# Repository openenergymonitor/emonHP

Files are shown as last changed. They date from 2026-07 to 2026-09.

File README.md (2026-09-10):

# emonHP - Heat Pump Monitoring

**As of Aug 2026 emonHP2 hardware is not yet released**

## Introduction

_emonHP V2_ is a system for monitoring heat pump operation. It is designed to work with [OpenEnergyMonitor](https://openenergymonitor.org), but can be used as a standalone system.

The system provides the following interfaces:

- MBUS
- RS485
- DHW, pulse, and OneWire (DS218B20 temperature) inputs
- USB-C power 
- 40-pin Raspberry Pi header
- OLED I2C display
- RFM69CW RF transceiver 

The board uses a STM32C031K6U microcontroller

## Getting started

### Getting a board

- Purchase a heat pump monitoring system from the [OpenEnergyMonitor Shop](https://shop.openenergymonitor.com/)
- Build your own!
  - With [KiCad](https://www.kicad.org/) installed, run `./generate.py` in the `pcb` directory (tested on Linux and macOS only) to generate manufacturing files (KiCad PCB, Gerbers, BoM).

### emonHP2

> [!NOTE]
Setting up as an integrated emonHP system requires a Raspberry Pi 4 or 5. These expose extra UART ports on the 40-pin header which are not available on older versions.

Connect the Raspberry Pi to the 40 pin header.

> [!WARNING]
Power must only be applied to one of the emonHP's USB-C port *or* the Raspberry Pi's power port, never both.

### Connections 

- DHW Status: Signal 1 input - GPIO27 - Pin 13 
- Pulse: Signal 2 input - GPIO22 - Pin15 - soft-pull down enabled (NOT TESTED)
- OneWire (DS18B20 ) - Signal 3 input - GPIO0*

\* Set `dtoverlay=w1-gpio,gpiopin=0` in `/boot/firmware/config.txt` to support OneWire on GPIO0

 - Push button - GPIO17 - pin11: set `push_btn = Button(17, pull_up=True, bounce_time=0.1, hold_time=5)` in `emonPiLCD2.py` 

### Firmware & Rasi Setup 

See firmware repo: https://github.com/openenergymonitor/emonhp-rs

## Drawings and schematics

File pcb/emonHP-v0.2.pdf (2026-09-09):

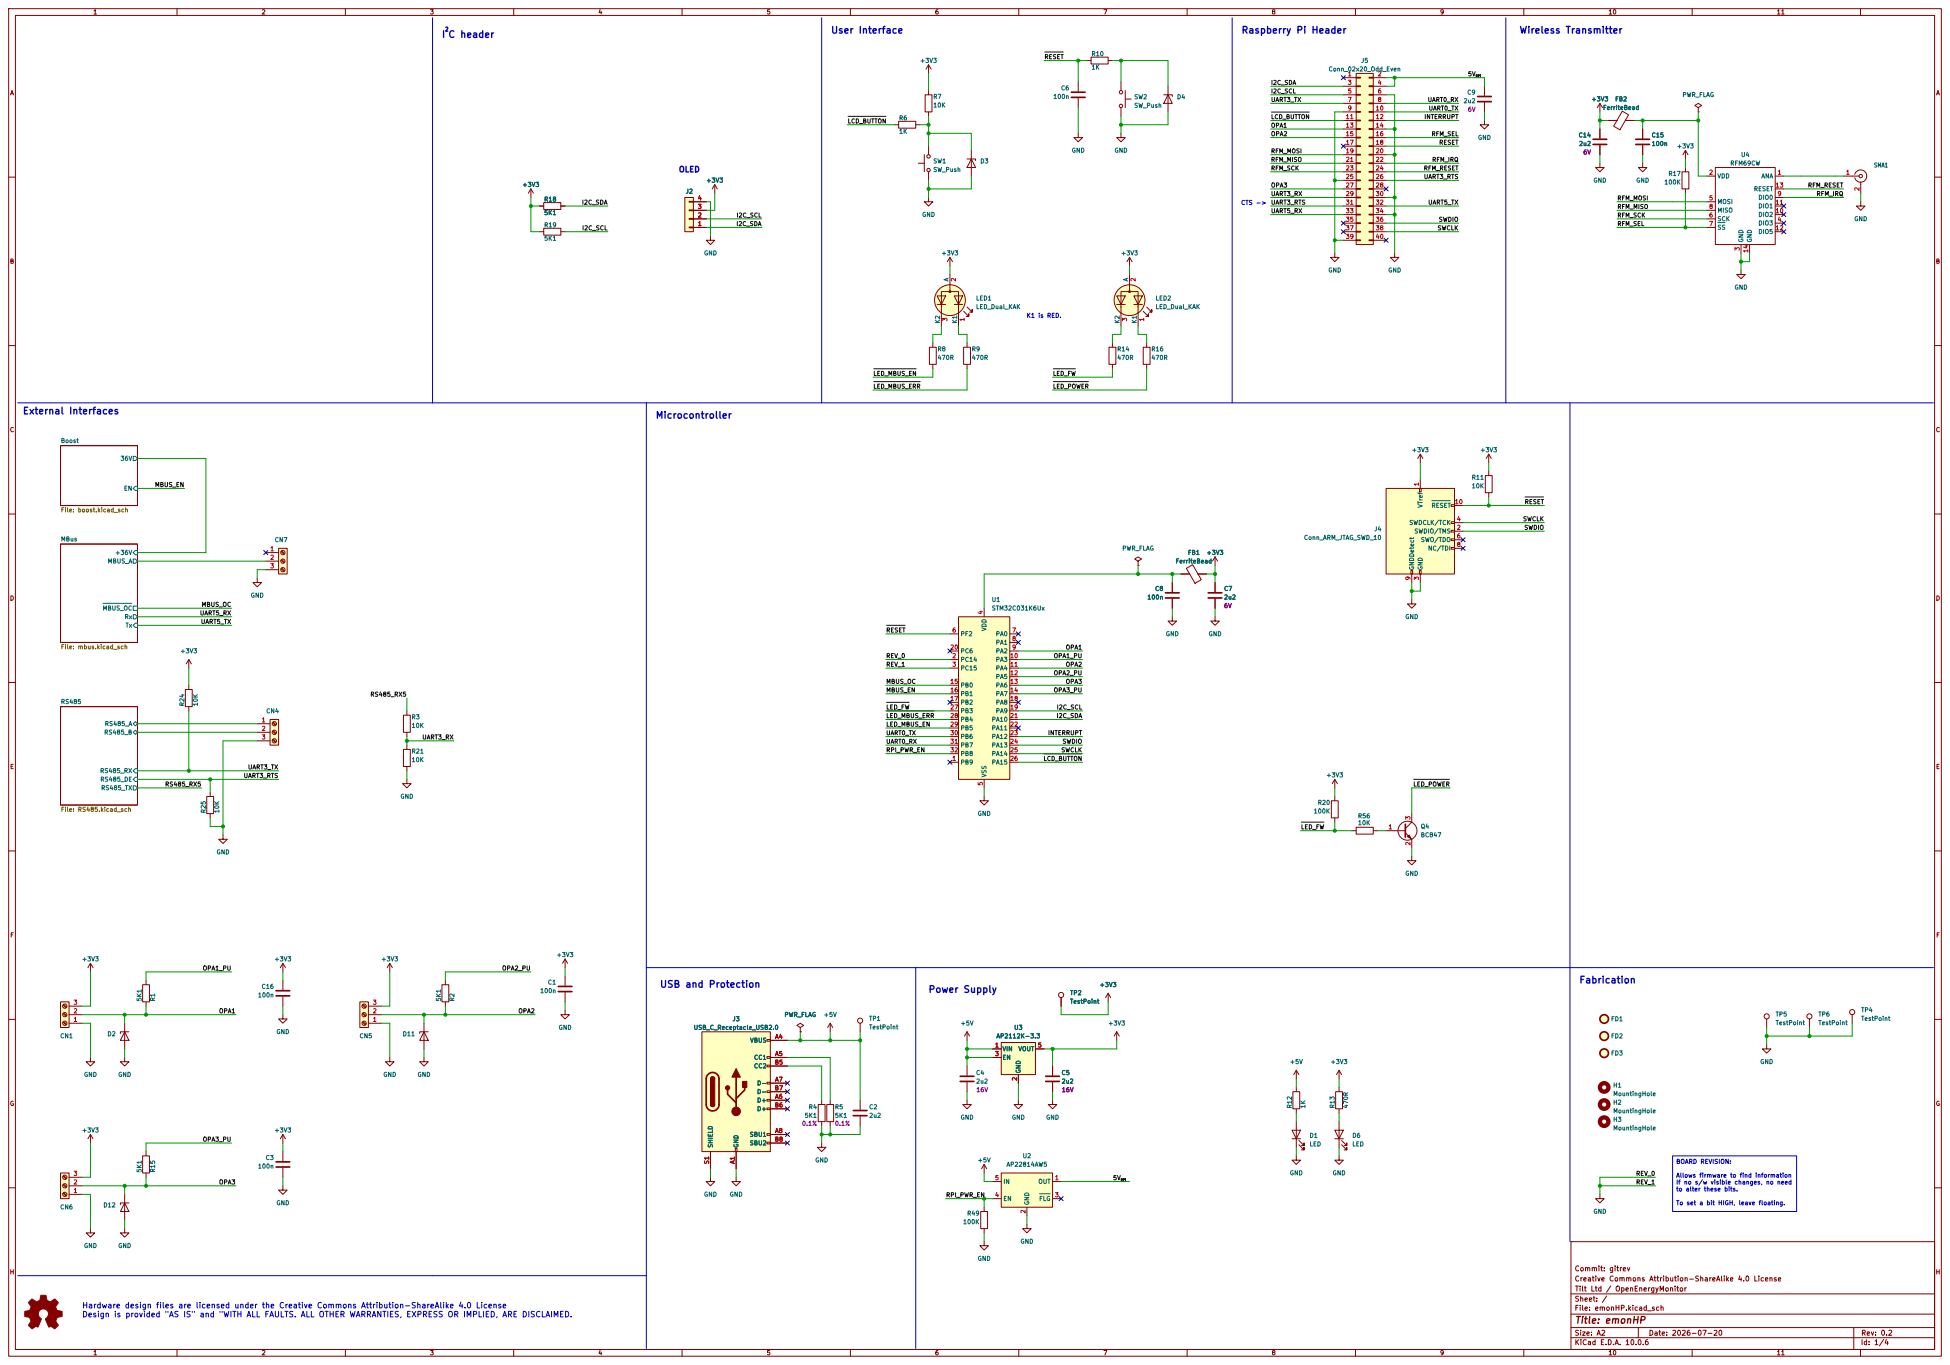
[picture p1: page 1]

USB and Protection PWR_FLAG | TestPoint+3V3 Power Supply TP2 TP2 VOUT 5 U3 AP2112K-3.3 AP2112K-3.3

SBU2 | B8 SHIELD S1

BOARD REVISION: Allows firmware to find information

to alter these bits. To set a bit HIGH, leave floating. Hardware design files are licensed under the Creative Commons Attribution-ShareAlike 4.0 License Design is provided "AS IS" and "WITH ALL FAULTS. ALL OTHER WARRANTIES, EXPRESS OR IMPLIED, ARE DISCLAIMED.

If no s/w visible changes, no need

Tilt Ltd / OpenEnergyMonitor Creative Commons Attribution-ShareAlike 4.0 License Commit: gitrev

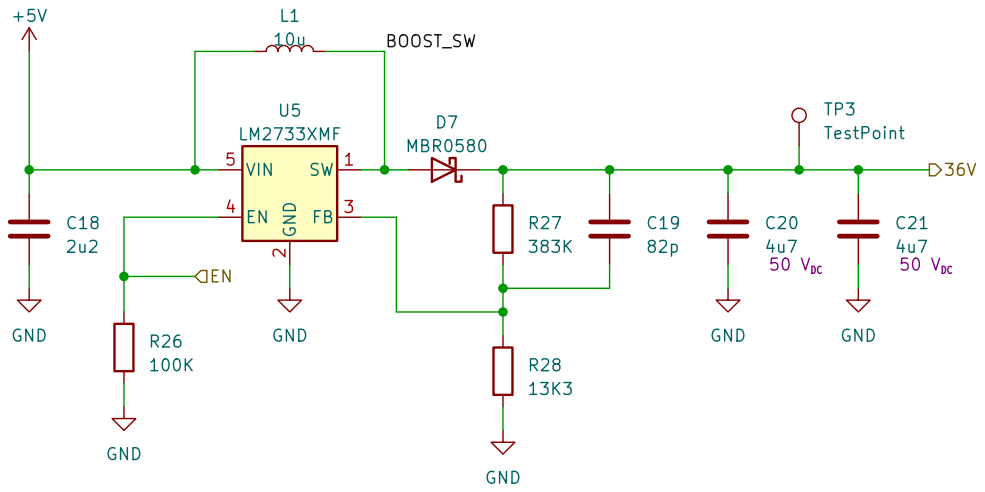
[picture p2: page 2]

File: boost.kicad_sch Sheet: /Boost/

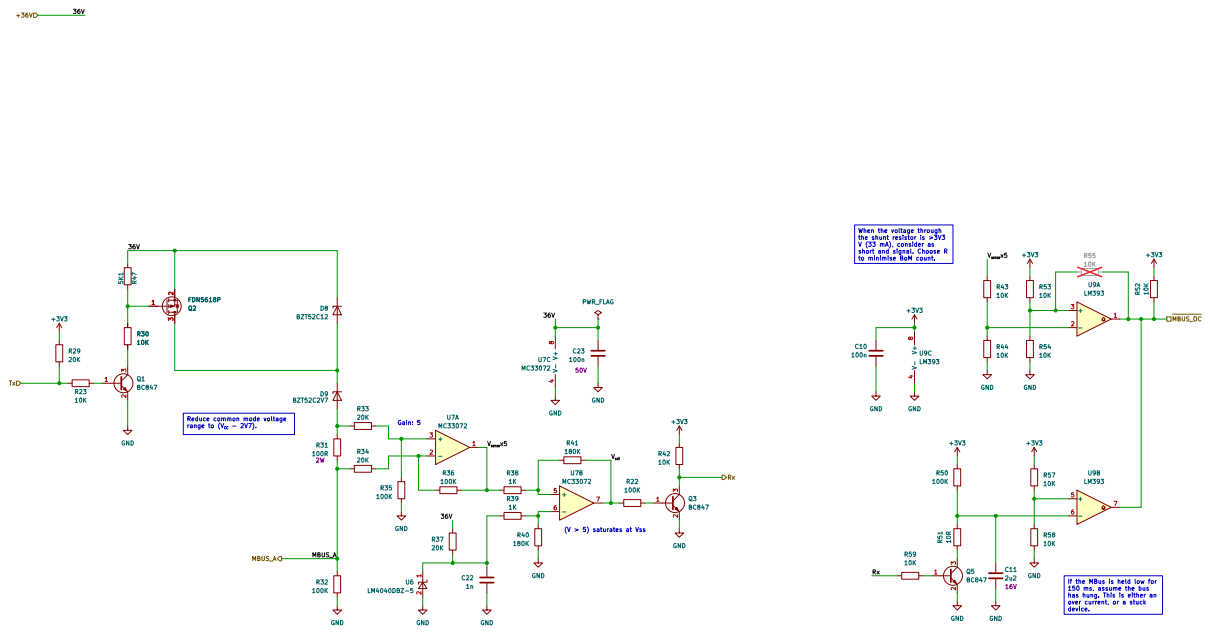
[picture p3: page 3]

the shunt resistor is >3V3
V (33 mA), consider as
short and signal. Choose R
to minimise BoM count.

Vsensex5 Reduce common mode voltage

over current, or a stuck device. (V > 5) saturates at Vss Gain: 5 Q2

If the MBus is held low for 150 ms, assume the bus has hung. This is either an

File: mbus.kicad_sch Sheet: /MBus/

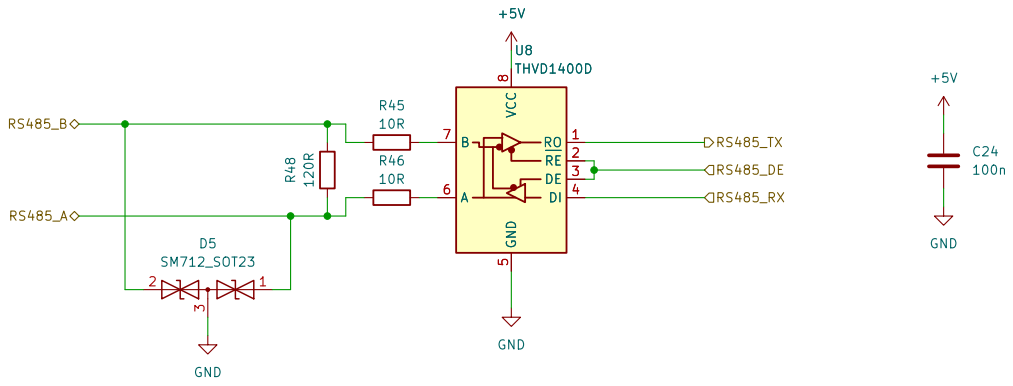
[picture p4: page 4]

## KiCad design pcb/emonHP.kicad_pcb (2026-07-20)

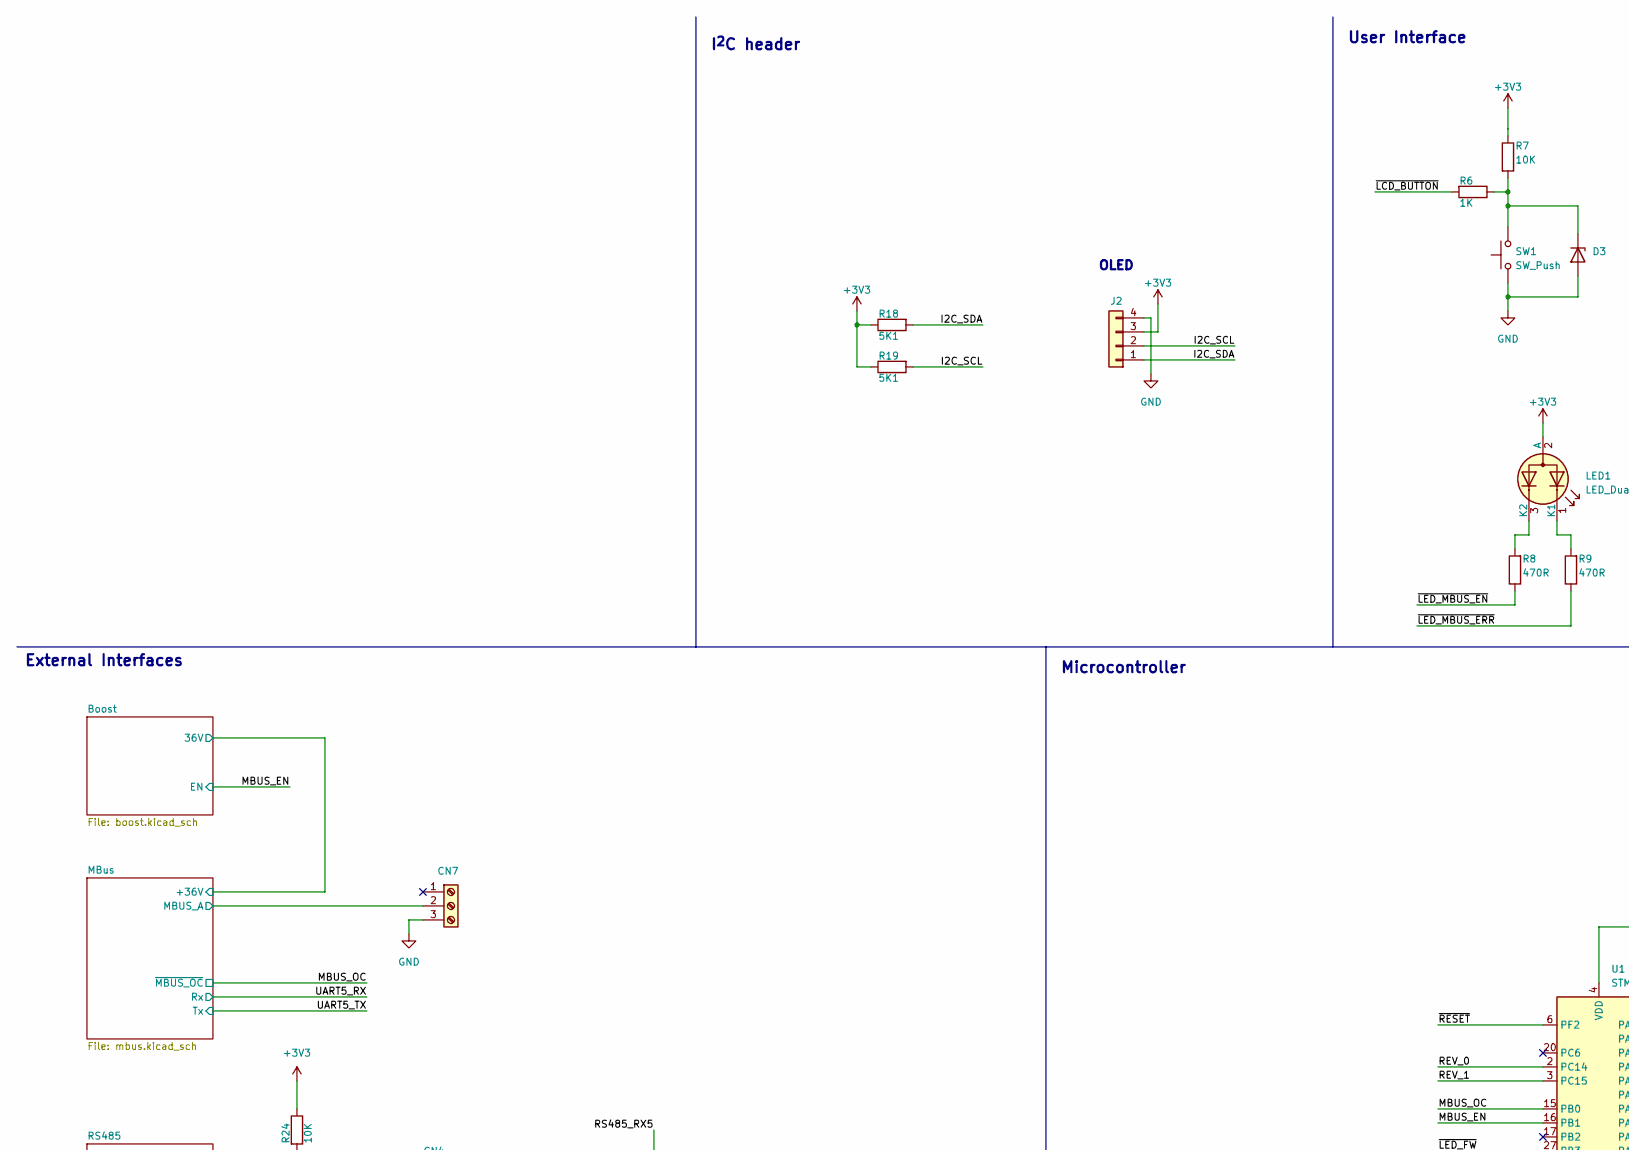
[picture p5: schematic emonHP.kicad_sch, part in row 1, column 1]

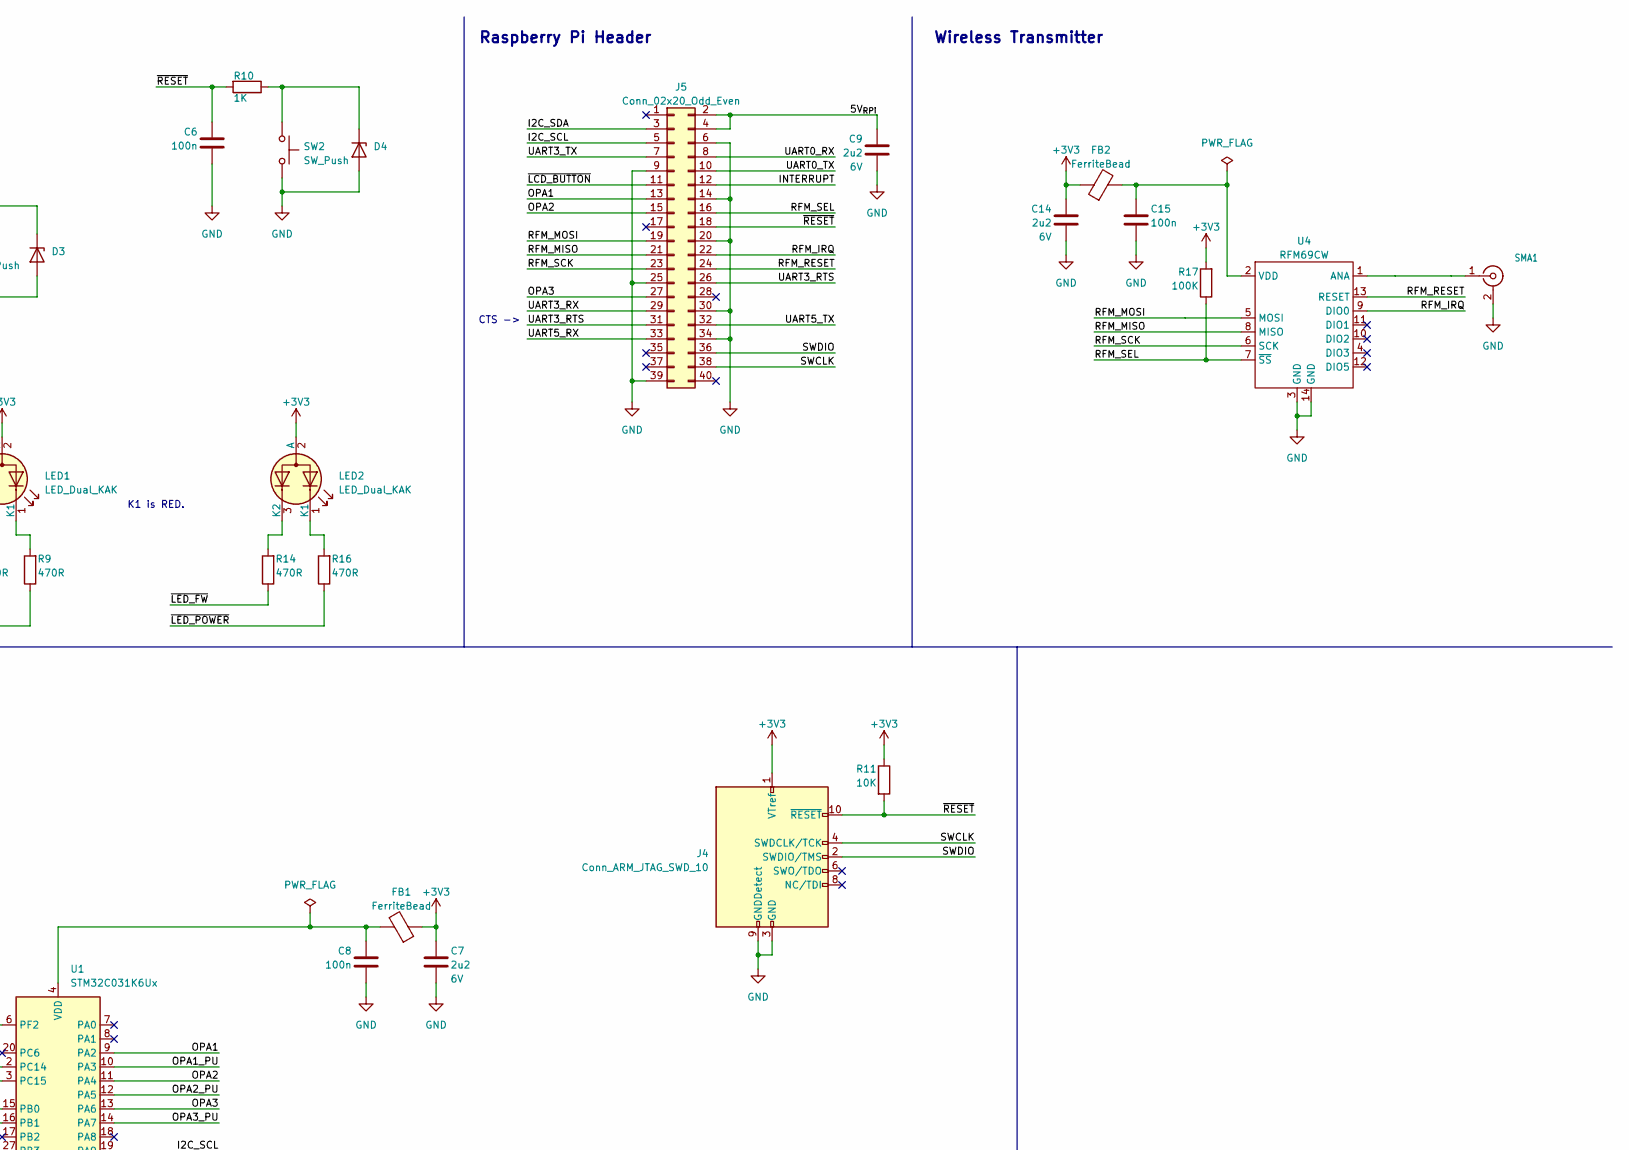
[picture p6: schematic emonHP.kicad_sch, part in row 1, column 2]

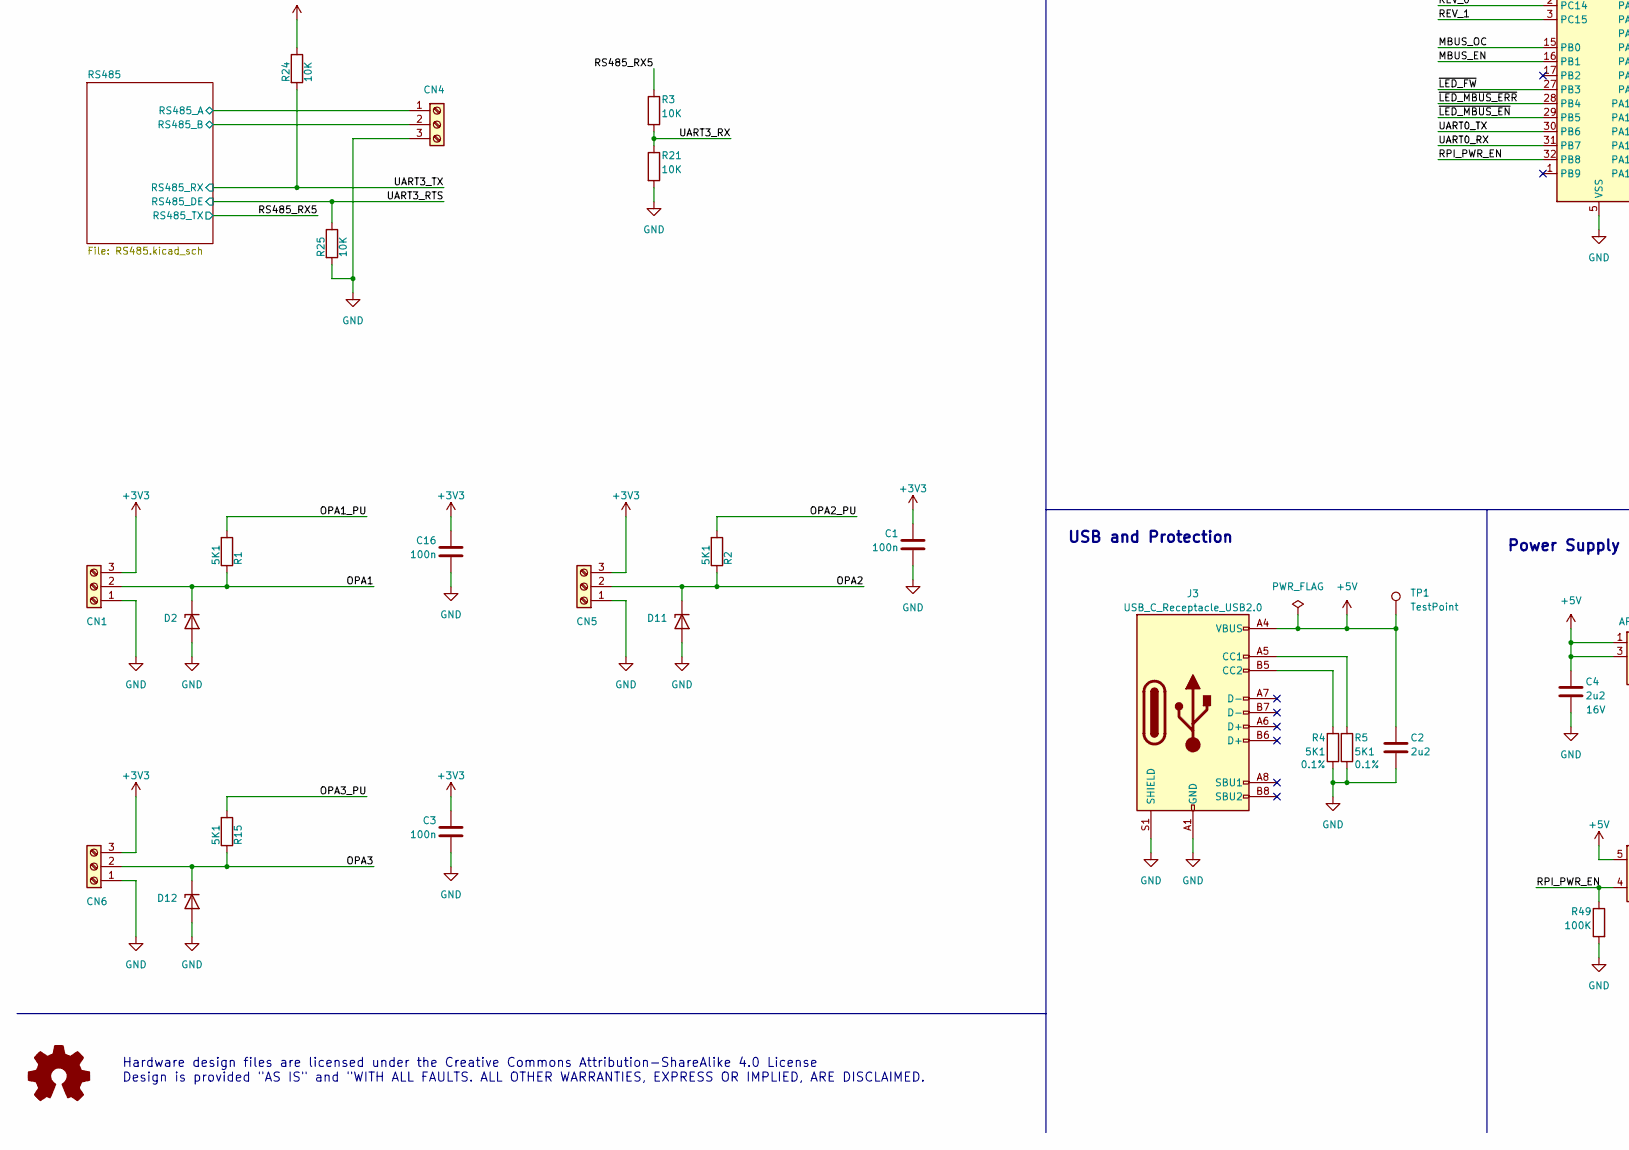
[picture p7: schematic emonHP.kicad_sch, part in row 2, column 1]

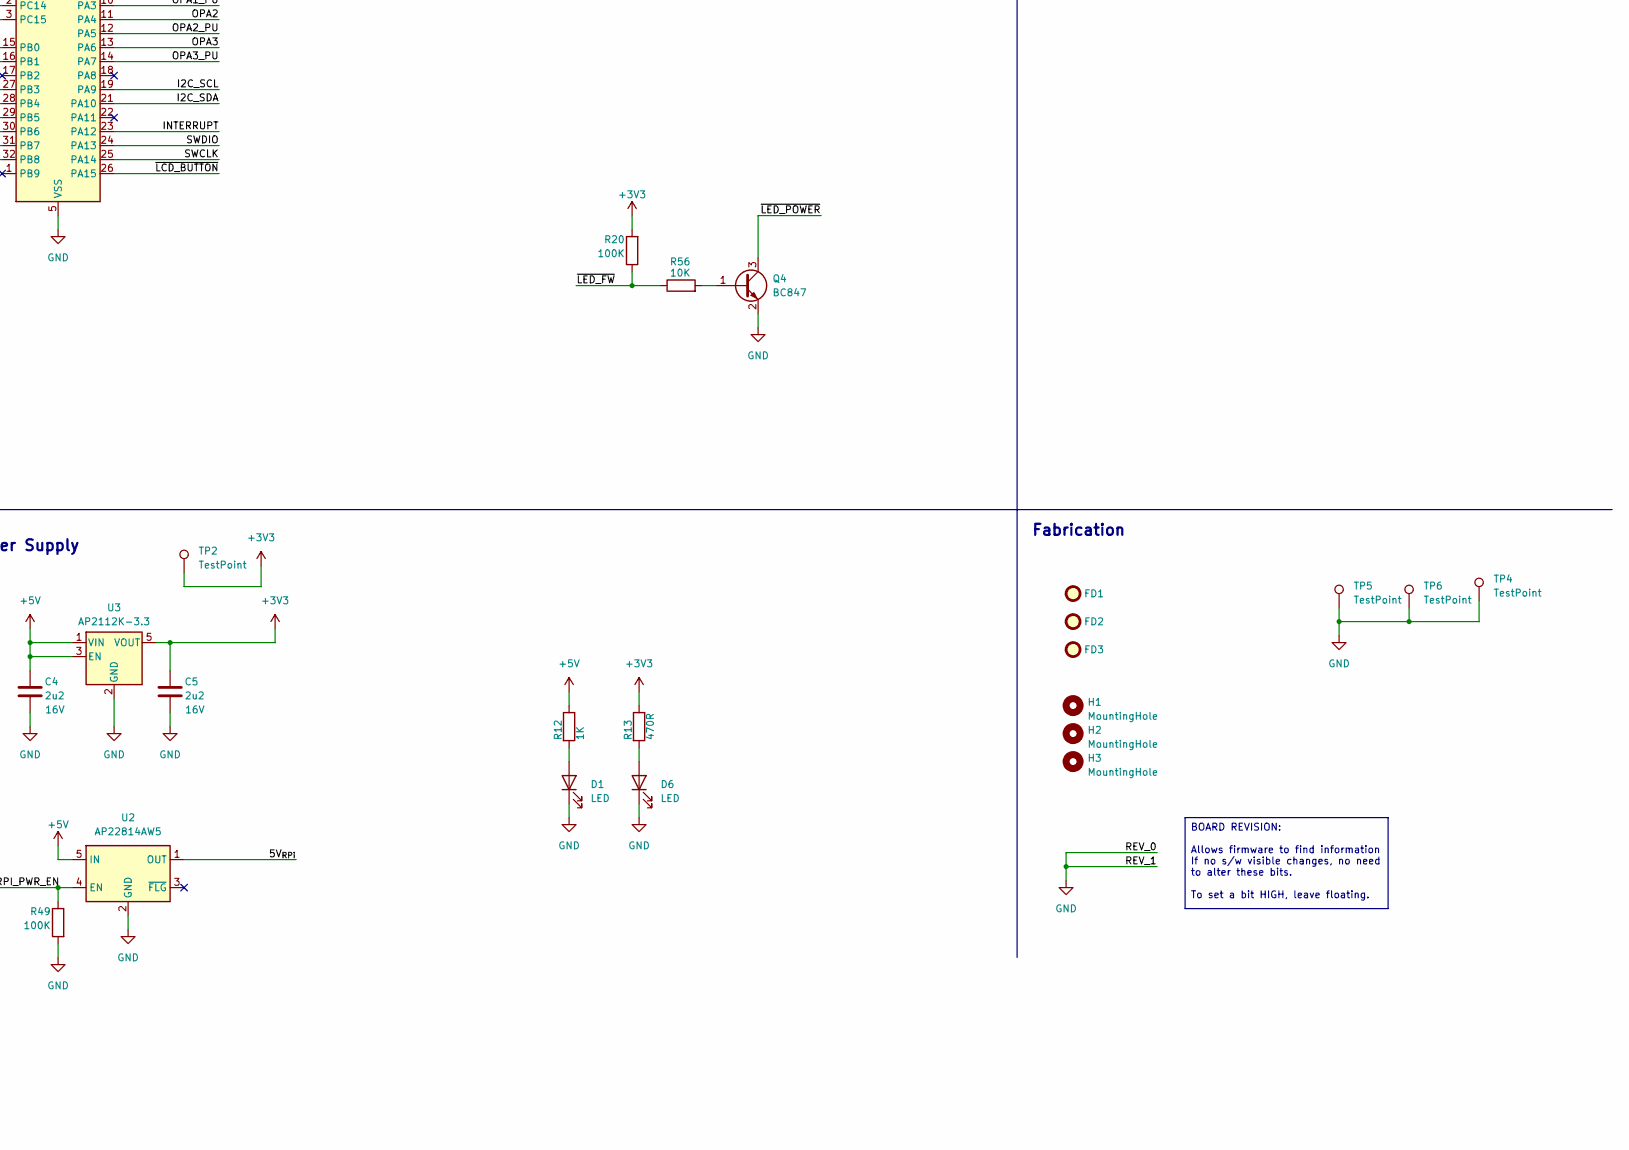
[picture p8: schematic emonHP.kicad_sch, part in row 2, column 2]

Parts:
C1, C3, C6, C8, C15, C16: 100n; C_0402_1005Metric; LCSC C1525
C2: 2u2; C_0402_1005Metric; LCSC C12530
C4, C5: 2u2; C_0603_1608Metric; Voltage 16V; LCSC C23630
C7, C9, C14: 2u2; C_0402_1005Metric; Voltage 6V; LCSC C12530
CN1, CN4, CN5, CN6, CN7: CONN_03SCREW; TerminalBlock_Phoenix_PT-1,5-3-3.5-H_1x03_P3.50mm_Horizontal; MPN 5441359; Mouser 651-5441359
D1, D6: LED; LED_0603_1608Metric; LCSC C2286
D2, D3, D4, D11, D12: ESD5Z3.3T5G; D_SOD-523; LCSC C22440024
FB1, FB2: FerriteBead; R_0402_1005Metric; LCSC C237347
FD1, FD2, FD3: FIDUCIAL1X2; Fiducial_0.75mm_Mask1.5mm
H1, H2: MountingHole; MountingHole_2.7mm_M2.5
H3: MountingHole; MountingHole_2.1mm
J2: CONN_04PTH; PinSocket_1x04_P2.54mm_Vertical
J3: USB_C_Receptacle_USB2.0; CSP-USC16-TR; LCSC C2765186
J4: Conn_ARM_JTAG_SWD_10; PinHeader_2x05_P1.27mm_Vertical_SMD; LCSC C150517
J5: Conn_02x20_Odd_Even; REF-182665; LCSC C9900171940
LED1, LED2: LED_Dual_KAK; LTST-S326; MPN LTST-S326KGJRKT; Mouser 859-LTST-S326KGJRKT
Q4: BC847; SOT-23; LCSC C2138
R1, R2, R15, R18, R19: 5K1; R_0402_1005Metric; LCSC C25905
R3, R7, R11, R21, R24, R25, R56: 10K; R_0402_1005Metric; LCSC C25744
R4, R5: 5K1; R_0402_1005Metric; Tolerance 0.1%; MPN ERA-3AED512V; Mouser 667-ERA-3AED512V
R6, R10, R12: 1K; R_0402_1005Metric; LCSC C11702
R8, R9, R13, R14, R16: 470R; R_0402_1005Metric; LCSC C25117
R17, R20, R49: 100K; R_0402_1005Metric; LCSC C25741
SMA1: SMACONNECTOR; SMA_Amphenol_132203-12_Horizontal
SW1: SW_Push; SW_PUSH_6mm
SW2: SW_Push; SW_Tactile_SPST_NO_Straight_CK_PTS636Sx25SMTRLFS; LCSC C2689642
TP1, TP2, TP4, TP5, TP6: TestPoint; TestPoint_Pad_D1.0mm
U1: STM32C031K6Ux; QFN-32-1EP_5x5mm_P0.5mm_EP3.45x3.45mm; LCSC C5456204
U2: AP22814AW5; SOT-23-5; LCSC C2680321
U3: AP2112K-3.3; SOT-23-5; LCSC C51118
U4: RFM69CW

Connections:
+3V3: C1.1, C3.1, C5.2, C7.1, C14.1, C16.1, CN1.3, CN5.3, CN6.3, FB1.1, FB2.1, J2.3, J4.1 (VTref), LED1.2 (A), LED2.2 (A), R7.1, R11.1, R13.1, R17.2, R18.1, R19.1, R20.2, R24.1, TP2.1, U3.5 (VOUT); also elsewhere on the board
+5V: C2.2, C4.2, J3.A4 (VBUS), J3.A9 (VBUS), J3.B4 (VBUS), J3.B9 (VBUS), R12.1, TP1.1, U2.5 (IN), U3.1 (VIN), U3.3 (EN); also elsewhere on the board
/5V_{RPi}: C9.1, J5.2, J5.4, U2.1 (OUT)
/I2C_SCL: J2.2, J5.5, R19.2, U1.19 (PA9)
/I2C_SDA: J2.1, J5.3, R18.2, U1.21 (PA10)
/INTERRUPT: J5.12, U1.23 (PA12)
/MBUS_EN: U1.16 (PB1); also elsewhere on the board
/MBUS_OC: U1.15 (PB0); also elsewhere on the board
/MBus/MBUS_A: CN7.2; also elsewhere on the board
/OPA1: CN1.2, D2.1 (K), J5.13, R1.1, U1.9 (PA2)
/OPA1_PU: R1.2, U1.10 (PA3)
/OPA2: CN5.2, D11.1 (K), J5.15, R2.1, U1.11 (PA4)
/OPA2_PU: R2.2, U1.12 (PA5)
/OPA3: CN6.2, D12.1 (K), J5.27, R15.1, U1.13 (PA6)
/OPA3_PU: R15.2, U1.14 (PA7)
/RFM_IRQ: J5.22, U4.9 (DIO0)
/RFM_MISO: J5.21, U4.8 (MISO)
/RFM_MOSI: J5.19, U4.5 (MOSI)
/RFM_RESET: J5.24, U4.13 (RESET)
/RFM_SCK: J5.23, U4.6 (SCK)
/RFM_SEL: J5.16, R17.1, U4.7 (~SS)
/RPI_PWR_EN: R49.1, U1.32 (PB8), U2.4 (EN)
/RS485/RS485_A: CN4.1; also elsewhere on the board
/RS485/RS485_B: CN4.2; also elsewhere on the board
/RS485_RX5: R3.1; also elsewhere on the board
/SWCLK: J4.4 (SWDCLK/TCK), J5.38, U1.25 (PA14)
/SWDIO: J4.2 (SWDIO/TMS), J5.36, U1.24 (PA13)
/UART0_RX: J5.8, U1.31 (PB7)
/UART0_TX: J5.10, U1.30 (PB6)
/UART3_RTS: J5.26, J5.31, R25.1; also elsewhere on the board
/UART3_RX: J5.29, R3.2, R21.1
/UART3_TX: J5.7, R24.2; also elsewhere on the board
/UART5_RX: J5.33; also elsewhere on the board
/UART5_TX: J5.32; also elsewhere on the board
/~LCD_BUTTON: J5.11, R6.2, U1.26 (PA15)
/~LED_FW: R14.1, R20.1, R56.1, U1.27 (PB3)
/~LED_MBUS_EN: R8.1, U1.29 (PB5)
/~LED_MBUS_ERR: R9.1, U1.28 (PB4)
/~LED_POWER: Q4.3 (C), R16.1
/~RESET: C6.1, J4.10 (~RESET), J5.18, R10.2, R11.2, U1.6 (PF2)
GND: C1.2, C2.1, C3.2, C4.1, C5.1, C6.2, C7.2, C8.2, C9.2, C14.2, C15.2, C16.2, CN1.1, CN4.3, CN5.1, CN6.1, CN7.3, D1.1 (K), D2.2 (A), D3.2 (A), D4.2 (A), D6.1 (K), D11.2 (A), D12.2 (A), J2.4, J3.A1 (GND), J3.A12 (GND), J3.B1 (GND), J3.B12 (GND), J3.S1 (SHIELD), J4.3 (GND), J4.5 (GND), J4.9 (GNDDetect), J5.6, J5.9, J5.14, J5.20, J5.25, J5.30, J5.34, J5.39, Q4.2 (E), R4.1, R5.1, R21.2, R25.2, R49.2, SMA1.2 (Ext), SW1.1, SW2.2, TP4.1, TP5.1, TP6.1, U1.2 (PC14), U1.3 (PC15), U1.5 (VSS), U1.33 (VSS), U2.2 (GND), U3.2 (GND), U4.3 (GND), U4.14 (GND); also elsewhere on the board
unnamed: D1.2 (A), R12.2
unnamed: D3.1 (K), R6.1, R7.2, SW1.2
unnamed: D4.1 (K), R10.1, SW2.1
unnamed: D6.2 (A), R13.2
unnamed: J3.A5 (CC1), R5.2
unnamed: J3.B5 (CC2), R4.2
unnamed: LED1.1 (K1), R9.2
unnamed: LED1.3 (K2), R8.2
unnamed: LED2.1 (K1), R16.2
unnamed: LED2.3 (K2), R14.2
unnamed: Q4.1 (B), R56.2
unnamed: SMA1.1 (In), U4.1 (ANA)
unnamed: C8.1, FB1.2, U1.4 (VDD)
unnamed: C15.1, FB2.2, U4.2 (VDD)

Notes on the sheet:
Raspberry Pi Header
Power Supply
CTS ->
Hardware design files are licensed under the Creative Commons Attribution-ShareAlike 4.0 License Design is provided "AS IS" and "WITH ALL FAULTS. ALL OTHER WARRANTIES, EXPRESS OR IMPLIED, ARE DISCLAIMED.
Microcontroller
User Interface
K1 is RED.
USB and Protection
Fabrication
OLED
External Interfaces
I^{2}C header
Wireless Transmitter
BOARD REVISION: Allows firmware to find information If no s/w visible changes, no need to alter these bits. To set a bit HIGH, leave floating.

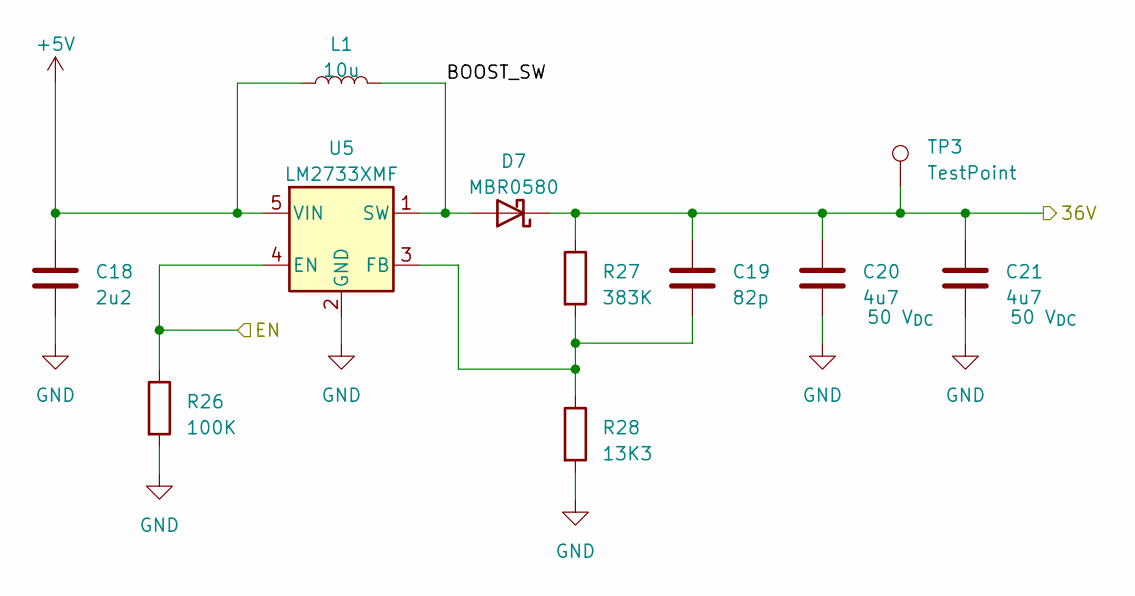
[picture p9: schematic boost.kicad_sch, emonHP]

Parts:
C18: 2u2; C_0603_1608Metric; LCSC C23630
C19: 82p; C_0603_1608Metric; LCSC C1683
C20, C21: 4u7; C_0805_2012Metric; Voltage 50 V_{DC}; MPN GRM21BZ71H475ME15L; LCSC C98192
D7: MBR0580; D_SOD-123; LCSC C177047
L1: 10u; L_Abracon_ASPI-3012S; MPN ASPI-3012S-100M-T; Mouser 815-ASPI-3012S-100MT
R26: 100K; R_0402_1005Metric; LCSC C25741
R27: 383K; R_0402_1005Metric; LCSC C25557
R28: 13K3; R_0402_1005Metric; LCSC C122547
TP3: TestPoint; TestPoint_Pad_D1.0mm
U5: LM2733XMF; SOT-23-5; MPN LM2733XMFX/NOPB; Mouser 926-LM2733XMFX/NOPB

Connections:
+5V: C18.1, L1.2, U5.5 (VIN); also elsewhere on the board
/Boost/BOOST_SW: D7.2 (A), L1.1, U5.1 (SW)
/MBUS_EN: R26.1, U5.4 (EN); also elsewhere on the board
/MBus/36V: C19.1, C20.1, C21.1, D7.1 (K), R27.1, TP3.1; also elsewhere on the board
GND: C18.2, C20.2, C21.2, R26.2, R28.2, U5.2 (GND); also elsewhere on the board
unnamed: C19.2, R27.2, R28.1, U5.3 (FB)

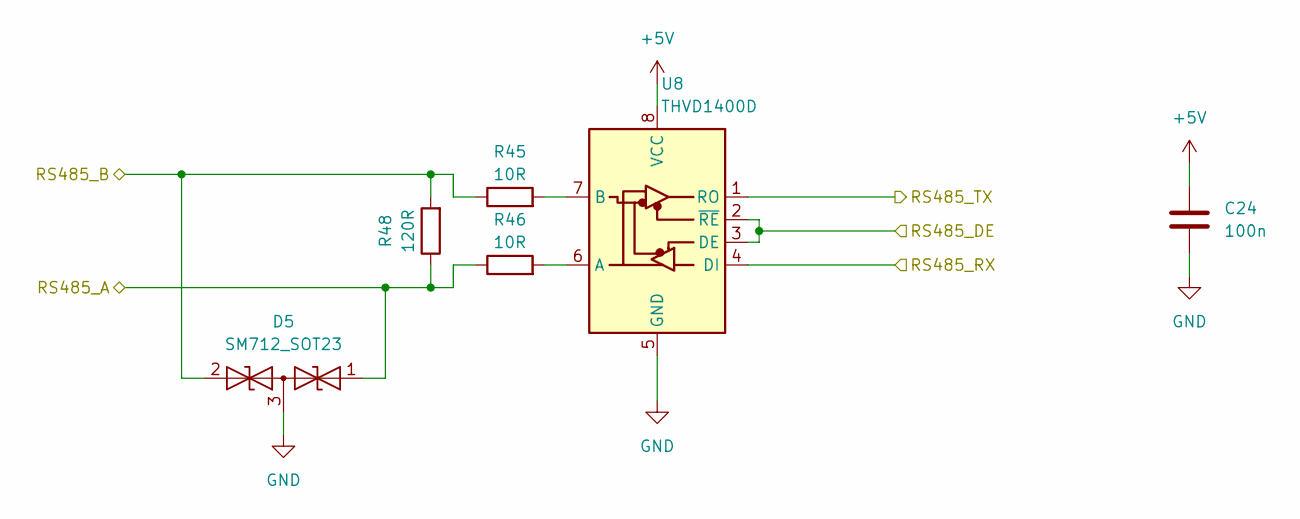
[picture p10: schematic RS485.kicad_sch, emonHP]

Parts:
C24: 100n; C_0402_1005Metric; LCSC C1525
D5: SM712_SOT23; SOT-23; LCSC C172881
R45, R46: 10R; R_0603_1608Metric; LCSC C22859
R48: 120R; R_1206_3216Metric; LCSC C17909
U8: THVD1400D; SOIC-8_3.9x4.9mm_P1.27mm; LCSC C3235232

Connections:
+5V: C24.1, U8.8 (VCC); also elsewhere on the board
/RS485/RS485_A: D5.1 (A1), R46.1, R48.1; also elsewhere on the board
/RS485/RS485_B: D5.2 (A2), R45.1, R48.2; also elsewhere on the board
/RS485_RX5: U8.1 (RO); also elsewhere on the board
/UART3_RTS: U8.2 (~RE), U8.3 (DE); also elsewhere on the board
/UART3_TX: U8.4 (DI); also elsewhere on the board
GND: C24.2, D5.3 (common), U8.5 (GND); also elsewhere on the board
unnamed: R46.2, U8.6 (A)
unnamed: R45.2, U8.7 (B)

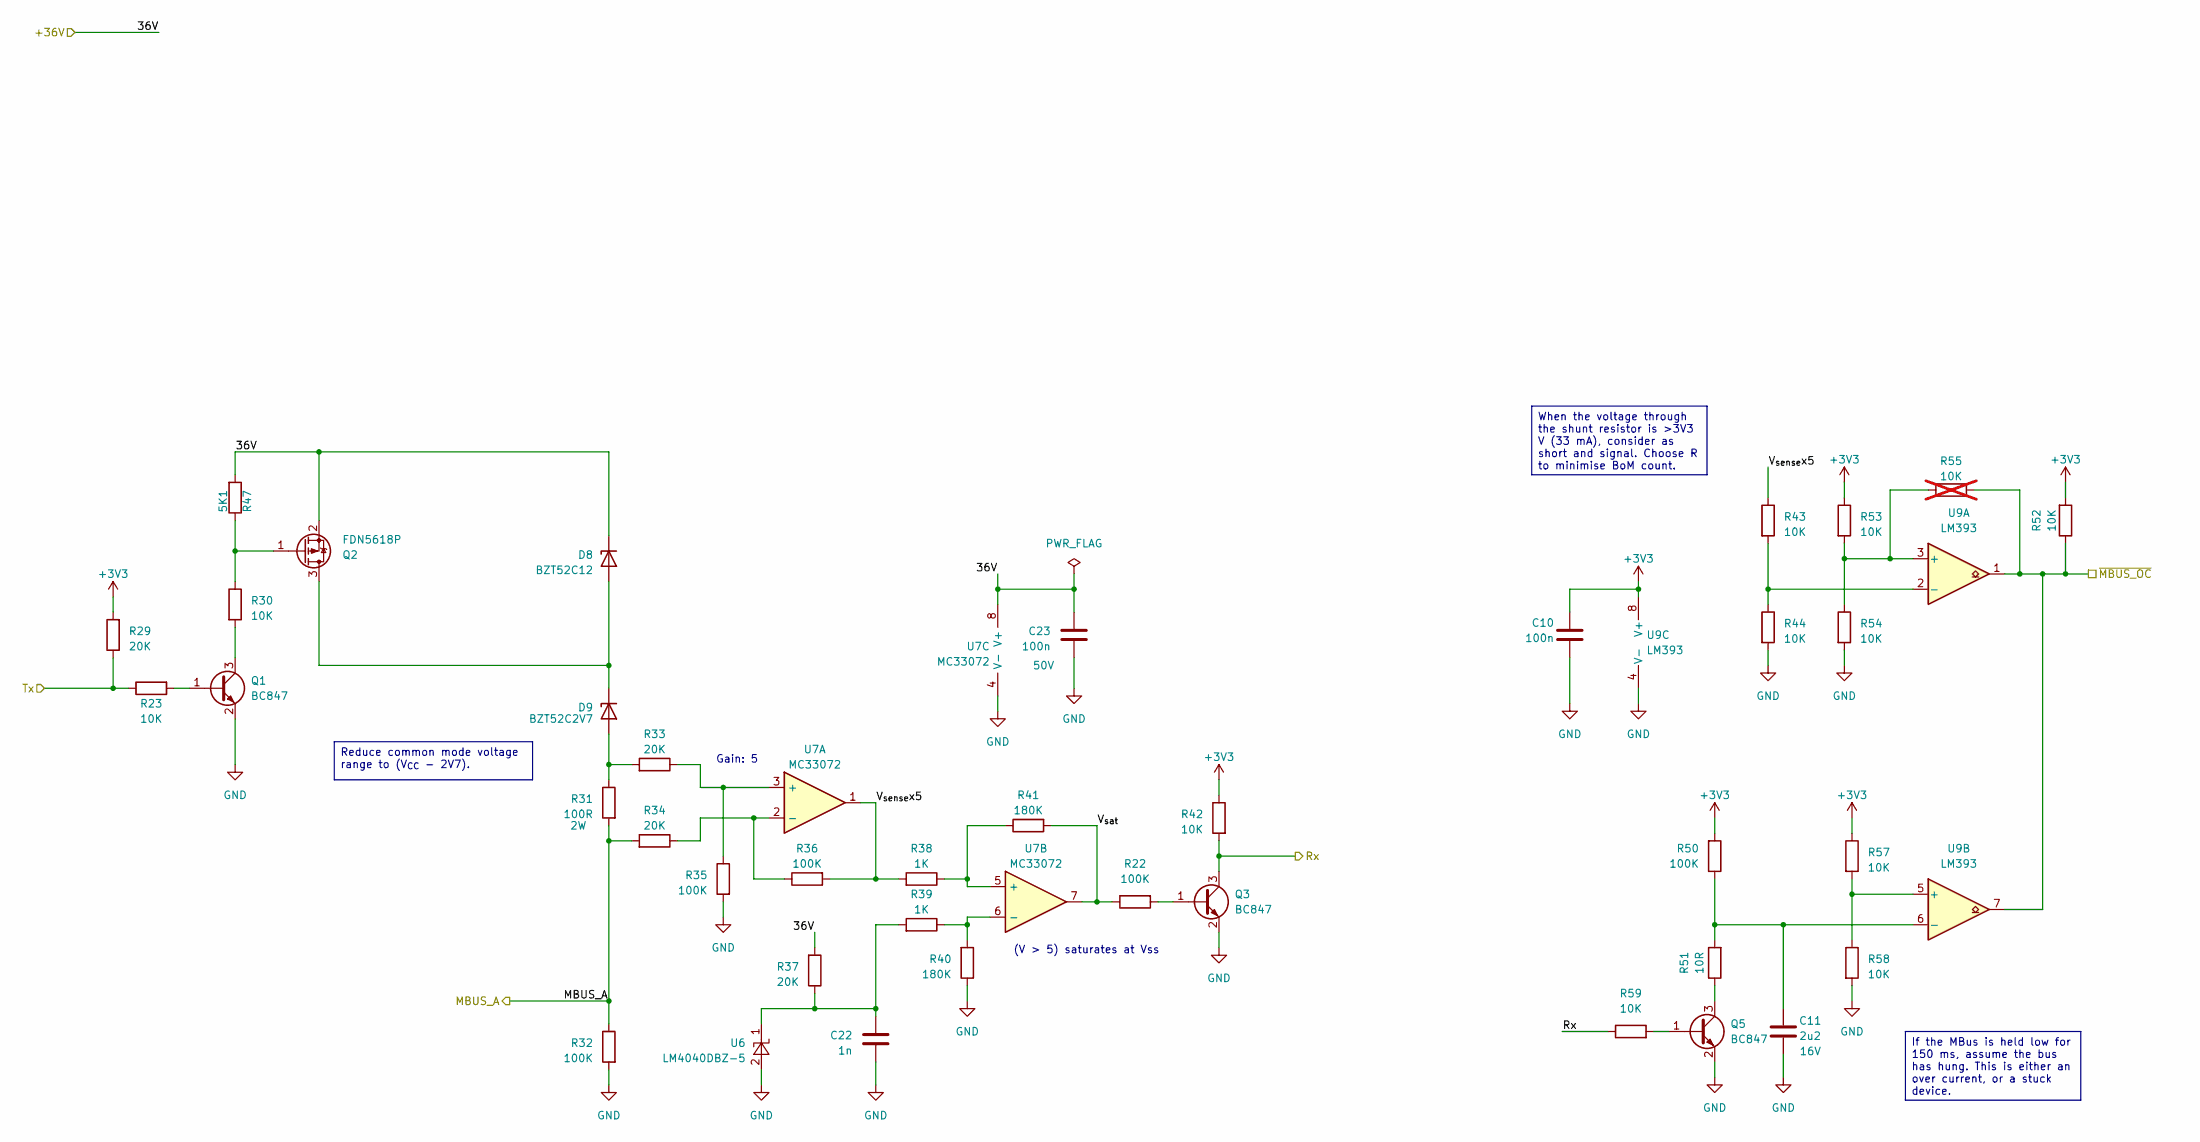
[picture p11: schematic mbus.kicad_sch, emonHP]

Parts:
C10: 100n; C_0402_1005Metric; LCSC C1525
C11: 2u2; C_0603_1608Metric; Voltage 16V; LCSC C23630
C22: 1n; C_0402_1005Metric; LCSC C1523
C23: 100n; C_0402_1005Metric; Voltage 50V; LCSC C307331
D8: BZT52C12; D_SOD-123F; LCSC C124196
D9: BZT52C2V7; D_SOD-123F; LCSC C5244698
Q1, Q3, Q5: BC847; SOT-23; LCSC C2138
Q2: FDN5618P; SOT-23; LCSC C400792
R22, R32, R35, R36, R50: 100K; R_0402_1005Metric; LCSC C25741
R23, R30, R42, R43, R44, R52, R53, R54, R57, R58, R59: 10K; R_0402_1005Metric; LCSC C25744
R29, R33, R34, R37: 20K; R_0402_1005Metric; LCSC C25765
R31: 100R; R_2512_6332Metric; MPN CRM2512-JW-101ELF; Mouser 652-CRM2512-JW101ELF
R38, R39: 1K; R_0402_1005Metric; LCSC C11702
R40, R41: 180K; R_0402_1005Metric; LCSC C25760
R47: 5K1; R_0402_1005Metric; LCSC C25905
R51: 10R; R_0603_1608Metric; LCSC C22859
R55: 10K; R_0402_1005Metric; LCSC C25744; not fitted
U6: LM4040DBZ-5; SOT-23; MPN LM4040DYM3-5.0-TR; Mouser 998-LM4040DYM3-5.0TR
U7: MC33072; SOIC-8_3.9x4.9mm_P1.27mm; MPN MC33072DR2G; Mouser 863-MC33072DR2G
U9: LM393; SOIC-8_3.9x4.9mm_P1.27mm; LCSC C7955

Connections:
+3V3: C10.1, R29.2, R42.1, R50.2, R52.2, R53.1, R57.1, U9.8 (V+); also elsewhere on the board
/MBUS_OC: R52.1, R55.2, U9.1, U9.7; also elsewhere on the board
/MBus/36V: C23.1, D8.1 (K), Q2.2 (S), R37.2, R47.2, U7.8 (V+); also elsewhere on the board
/MBus/MBUS_A: R31.2, R32.1, R34.2; also elsewhere on the board
/MBus/V_{sat}: R22.1, R41.2, U7.7
/MBus/V_{sense}x5: R36.2, R38.2, R43.1, U7.1
/UART5_RX: Q3.3 (C), R42.2, R59.1; also elsewhere on the board
/UART5_TX: R23.1, R29.1; also elsewhere on the board
GND: C10.2, C11.1, C22.2, C23.2, Q1.2 (E), Q3.2 (E), Q5.2 (E), R32.2, R35.2, R40.1, R44.2, R54.2, R58.2, U6.2 (A), U7.4 (V-), U9.4 (V-); also elsewhere on the board
unnamed: D8.2 (A), D9.1 (K), Q2.3 (D)
unnamed: D9.2 (A), R31.1, R33.2
unnamed: Q1.1 (B), R23.2
unnamed: Q1.3 (C), R30.2
unnamed: Q2.1 (G), R30.1, R47.1
unnamed: Q3.1 (B), R22.2
unnamed: Q5.1 (B), R59.2
unnamed: Q5.3 (C), R51.1
unnamed: C22.1, R37.1, R39.2, U6.1 (K)
unnamed: R33.1, R35.1, U7.3 (+)
unnamed: R34.1, R36.1, U7.2 (-)
unnamed: R38.1, R41.1, U7.5 (+)
unnamed: R39.1, R40.2, U7.6 (-)
unnamed: R53.2, R54.1, R55.1, U9.3 (+)
unnamed: R43.2, R44.1, U9.2 (-)
unnamed: R57.2, R58.1, U9.5 (+)
unnamed: C11.2, R50.1, R51.2, U9.6 (-)

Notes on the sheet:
Gain: 5
(V > 5) saturates at Vss
When the voltage through the shunt resistor is >3V3 V (33 mA), consider as short and signal. Choose R to minimise BoM count.
If the MBus is held low for 150 ms, assume the bus has hung. This is either an over current, or a stuck device.
Reduce common mode voltage range to (V_{CC} - 2V7).

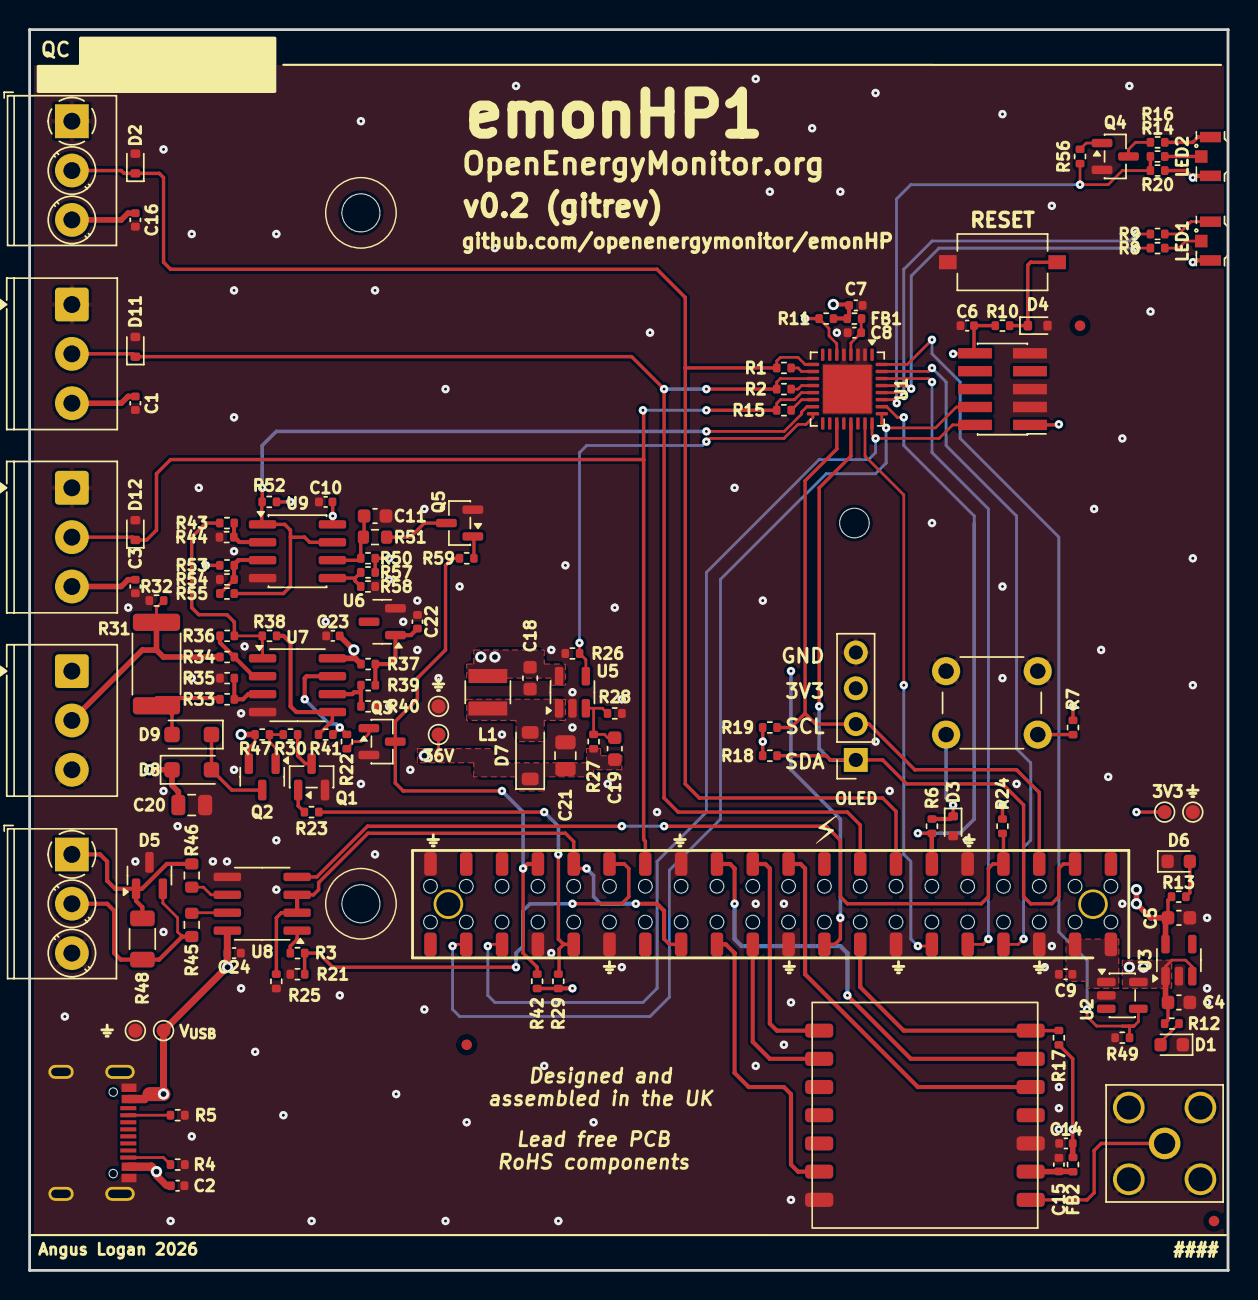
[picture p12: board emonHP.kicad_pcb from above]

Board: 4 copper layers, 85.0 x 88.0 mm, 134 parts (0 on the bottom side), 79 nets.

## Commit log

2025-07-29 Manufactured board
    [ACDetect.kicad_sch, ASPI-3012S-100M-T.stp, RS485.kicad_sch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]
2026-04-13 emonHP with Pi attachment
    [ACDetect.kicad_sch, RS485.kicad_sch, boost.kicad_sch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]
2026-07-20 [0.2] Freeze for manufacture
    [RS485.kicad_sch, boost.kicad_sch, emonHP.kicad_pcb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]
2026-08-08 [Readme] Update for v0.2 board
    [ACDetect.kicad_sch, ct_frontend.kicad_sch]
2026-09-10 Update README with push button GPIO17 setup
    Added push button configuration details for GPIO17.
